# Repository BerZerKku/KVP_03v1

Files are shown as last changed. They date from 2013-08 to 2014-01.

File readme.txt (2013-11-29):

Плата KVP_03v1.
Сделана в OrCAD 16.6.

Предназначена для использования в АВАНТ К400 и АВАНТ Р400М вместе с сэндвич-
панелями.

Основной вариант:
используется для Р400М
отсутствуют: цифровая ретрансляция, выходы ком.ПРД/ПРМ, вход ПУСК

Вариант К400:
используется для К400
плата запаивается полностью

На данный момент входы управления запаиваются под 24В.

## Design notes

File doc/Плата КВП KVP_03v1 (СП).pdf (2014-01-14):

№ | Наименование | Корпус | Кол. | Поз. | Примечание

# 2 АВАНТ КВП v3.1 СП

Изм | Лист | № докум. | Подп. | Дата
Разраб. | Щеблыкин М.В | | 14-01-14 | Плата КВП 03v1 Спецификация | Лит. | Лист | Листов
Провер. | Вершинин А.С. | | | | | 1 | 5

### ООО «Прософт-Системы»

Н.контр. | Назаренко А.Н.
Утв. | Чирков А.Г.

1 Сборочный чертеж
| АВАНТ КВП v3.1 rev.2 | 1

ДЕТАЛИ

3 Плата печатная
| KVP_03v1 | 1

ПРОЧИЕ ИЗДЕЛИЯ

Диоды

5 1N4148WS FAIRCHILD
| (1N4148WS-V VISHAY) | SOD-323 | 2 | VD21,VD24

7 Супрессор SM6T6V8CA 6.8В
| двунаправленный | DO-214AA | 11 | VD1-VD8,VD20,VD23,VD27

9 Супрессор SM6T18A 18В
| однонаправленный | DO-214AA | 2 | VD22,VD25

11 Супрессор SM6T30CA 30В
| двунаправленный | DO-214AA | 1 | VD26

13 Супрессор SMBJ300CA 300B
| двунаправленный | DO-214AA | 2 | VD13,VD14

Конденсаторы

17 | чип 0805 X7R 50В 0.01мкФ ±10% | 0805 | 4 | C5,C8,C14,C17
19 | чип 0805 X7R 50В 0.1мкФ ±10% | 0805 | 14 | C1,C3,C4,C6,C9,C10,C12,C13,C15,C18,
| | | | C28,C29,C32,C34
21 | чип 1206 X7R 50В 0.1мкФ ±10% | 1206 | 2 | C33,C35
23 | чип 1210 X7R 25В 10мкФ ±10% | 1210 | 4 | C2,C7,C11,C16

| | | | | АВАНТ КВП v3.1 | Лист 2 Изм
2
| Лист | № докум. | Подп. | Дата

Микросхемы

27 | ADM2587EBRWZ 500kB AD | SOIC_20 | 2 | DD2,DD4

29 SN74LVC1G14DBV(R, T) TI
| (74LVC1G14GV PANASONIC, NXP) | SOT-23_5 | 2 | DD1,DD3

31 ULN280ADW TI (ULN2803ADWR TI,
| ULN2803AFWG TOSHIBA) | SOIC_18 | 1 | DD7
35 | Оптрон ACPL-M50L-500E AVAGO | SMD_5 | 2 | AV2,AV3

39 Переключатель SmWDL-02
| DIPTRONICS | SMD_4 | 4 | S1-S4

Разъемы

43 | 231-576/001-000 WAGO | 16 pins | 2 | X2,X3
45 | DIN 41612 3*32 64 MR | 64 pins | 1 | X1 | вилка угловая
47 | PLS-2 | PLS_2 | 2 | X4,X5

Резисторы

51 | чип 0805 10Ом ±5% | 0805 | 8 | R5,R8-R10,R17,R20-R22
53 | чип 0805 51Ом ±5% | 0805 | 2 | R6,R18
55 | чип 0805 100Ом ±5% | 0805 | 4 | R3,R4,R15,R16 | не устанавл.
57 | чип 0805 120Ом ±5% | 0805 | 2 | R7,R19
59 | чип 0805 470Ом ±5% | 0805 | 4 | R11,R12,R23,R24
61 | чип 2010 470Ом ±5% | 2010 | 4 | R49,R56,R57,R64
63 | чип 2010 1кОм ±5% | 2010 | 4 | R51,R54,R59,R62
65 | чип 2010 1.2кОм ±5% | 2010 | 2 | R52,R60
67 | чип 0805 2кОм ±5% | 0805 | 2 | R53,R61

| | | | 3 Изм
Лист | № докум. | Подп. | Дата

69 SQM500JB-5K1 5.1кОм 5Вт ±5%
| YAGEO | 2 pins | 6 | R42,R47,R50,R55,R58,R63 | не устанавл.
71 | чип 0805 6.2кОм ±5% | 0805 | 1 | R37
73 | чип 0805 10кОм ±5% | 0805 | 4 | R1,R2,R13,R14

77 Реле D3212 FX2 24VDC AXICOM
| (G6S-2-24DC OMRON) | 8 pins | 1 | K1

81 Ферритовая бусина
| BLM31PG601SN1 MURATA | 1206 | 8 | FB1-FB8
83 | Провод МГТФ 0.05 (0.03-0.12) | 0.2м | для доработки

Переменные данные для
исполнений:

ВАРИАНТ К400

Диоды

5 1N4148WS FAIRCHILD
| (1N4148WS-V VISHAY) | SOD-323 | 1 | VD19

7 Супрессор SM6T6V8CA 6.8В
| двунаправленный | DO-214AA | 5 | VD9-VD12,VD17

9 Супрессор SM6T18A 18В
| однонаправленный | DO-214AA | 1 | VD18

13 Супрессор SMBJ300CA 300B
| двунаправленный | DO-214AA | 3 | VD14-VD16

Конденсаторы

17 | чип 0805 X7R 50В 0.01мкФ ±10% | 0805 | 2 | C23,C26
19 | чип 0805 X7R 50В 0.1мкФ ±10% | 0805 | 6 | C19,C21,C22,C24,C27,C30
21 | чип 1206 X7R 50В 0.1мкФ ±10% | 1206 | 1 | C31
23 | чип 1210 X7R 25В 10мкФ ±10% | 1210 | 2 | C20,C25

| | | | 4 Изм
Лист | № докум. | Подп. | Дата

Микросхемы

27 | ADM2587EBRWZ 500kB AD | SOIC_20 | 1 | DD6

29 SN74LVC1G14DBV(R, T) TI
| (74LVC1G14GV PANASONIC, NXP) | SOT-23_5 | 1 | DD5
35 | Оптрон ACPL-M50L-500E AVAGO | SMD_5 | 1 | AV1

39 Переключатель SmWDL-02
| DIPTRONICS | SMD_4 | 2 | S5,S6

Резисторы

51 | чип 0805 10Ом ±5% | 0805 | 4 | R29,R32-R34
53 | чип 0805 51Ом ±5% | 0805 | 1 | R30
55 | чип 0805 100Ом ±5% | 0805 | 2 | R27,R28
57 | чип 0805 120Ом ±5% | 0805 | 1 | R31
59 | чип 0805 470Ом ±5% | 0805 | 2 | R35,R36
61 | чип 2010 470Ом ±5% | 2010 | 2 | R41,R48
63 | чип 2010 1кОм ±5% | 2010 | 2 | R45,R46
65 | чип 2010 1.2кОм ±5% | 2010 | 1 | R43
67 | чип 0805 2кОм ±5% | 0805 | 1 | R44
71 | чип 0805 6.2кОм ±5% | 0805 | 3 | R38-R40
73 | чип 0805 10кОм ±5% | 0805 | 2 | R25,R26

77 Реле D3212 FX2 24VDC AXICOM
| (G6S-2-24DC OMRON) | 8 pins | 3 | К2-K4

81 Ферритовая бусина
| BLM31PG601SN1 MURATA | 1206 | 4 | FB9-FB12

| | | | 5 Изм
Лист | № докум. | Подп. | Дата

### Лист регистрции ревизий СП

№ ревизии | № замененных (измененных) страниц | Дата ревизии | Краткое содержание и причина внесения изменений | Примечание
0 | вновь | 28.11.13
1 | 1-4 | 13.12.13 | Элементы K2 поз.77, VD14 поз.13, R38-R40 поз.71 перенесены в вариант К400.
2 | 1,3 | 09.01.14 | Добавлен провод поз.83 Поз.55 в основом варианте не устанавливать. Изменен номер ревизии СБ.

### Лист регистрции ревизий СБ

№ ревизии | № замененных (измененных) страниц | Дата ревизии | Краткое содержание и причина внесения изменений | Примечание
0 | вновь | 28.11.13
1 | 1 | 13.12.13 | Наименование документа изменено на «Плата КВП 03v1».
2 | 1 | 09.01.14 | Добавлена доработка сигналов телемеханики и локальной сети. Добавлена доработка подтяжек в интерфейсах.

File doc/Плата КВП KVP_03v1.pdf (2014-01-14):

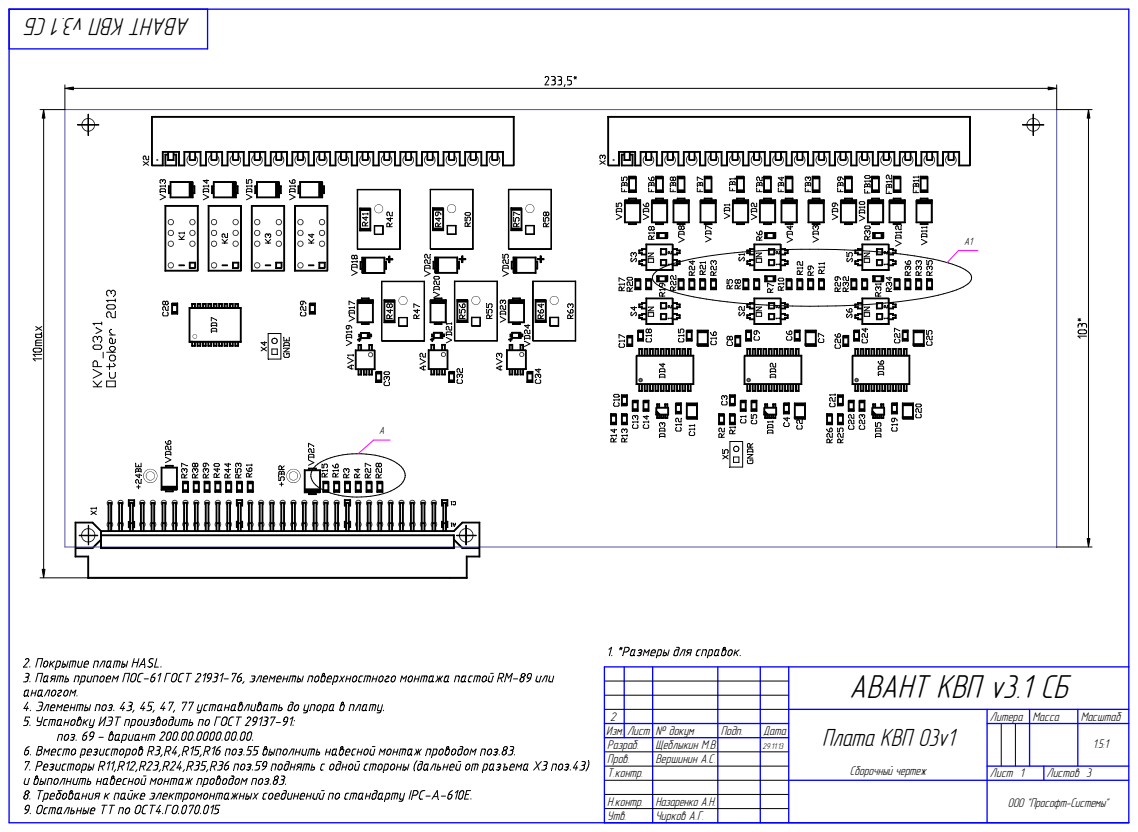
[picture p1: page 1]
Ëèñòîâ 3; Ìàññà; Ìàñøòàá; Ïîäï.; Äàòà; Óòâ.; Í.êîíòð.; Ò.êîíòð.; Ïðîâ.; Ðàçðàá.; Èçì. Ëèñò; ×èðêîâ À.Ã.; Íàçàðåíêî À.Í.; Âåðøèíèí À.Ñ.; Ùåáëûêèí Ì.Â.; № äîêóì; Ëèñò 1; Ëèòåðà; Ïëàòà ÊÂÏ 03v1

ÀÂÀÍÒ ÊÂÏ v3.1 ÑÁ

Ñáîðî÷íûé ÷åðòåæ

ÎÎÎ "Ïðîñîôò-Ñèñòåìû"

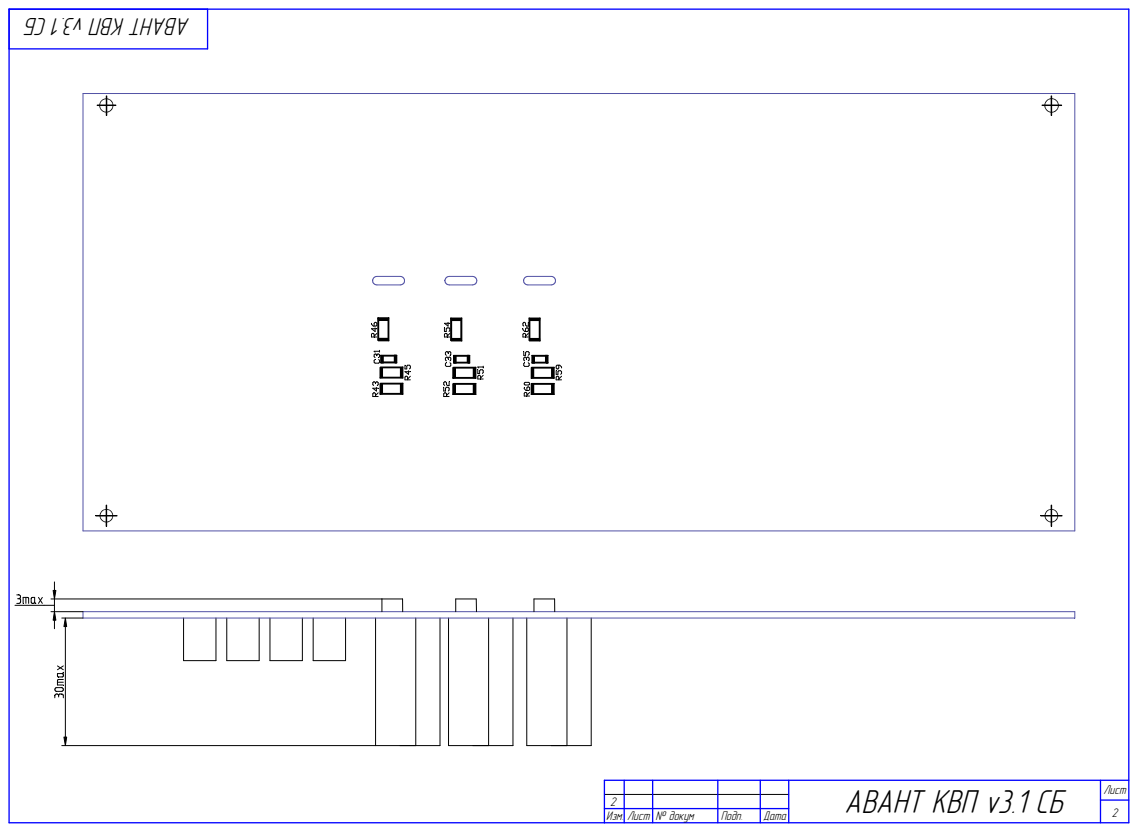
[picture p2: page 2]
Ëèñò; Èçì. Ëèñò № äîêóì; Ïîäï.; Äàòà; ÀÂÀÍÒ ÊÂÏ v3.1 ÑÁ

À (5:1), ï.6

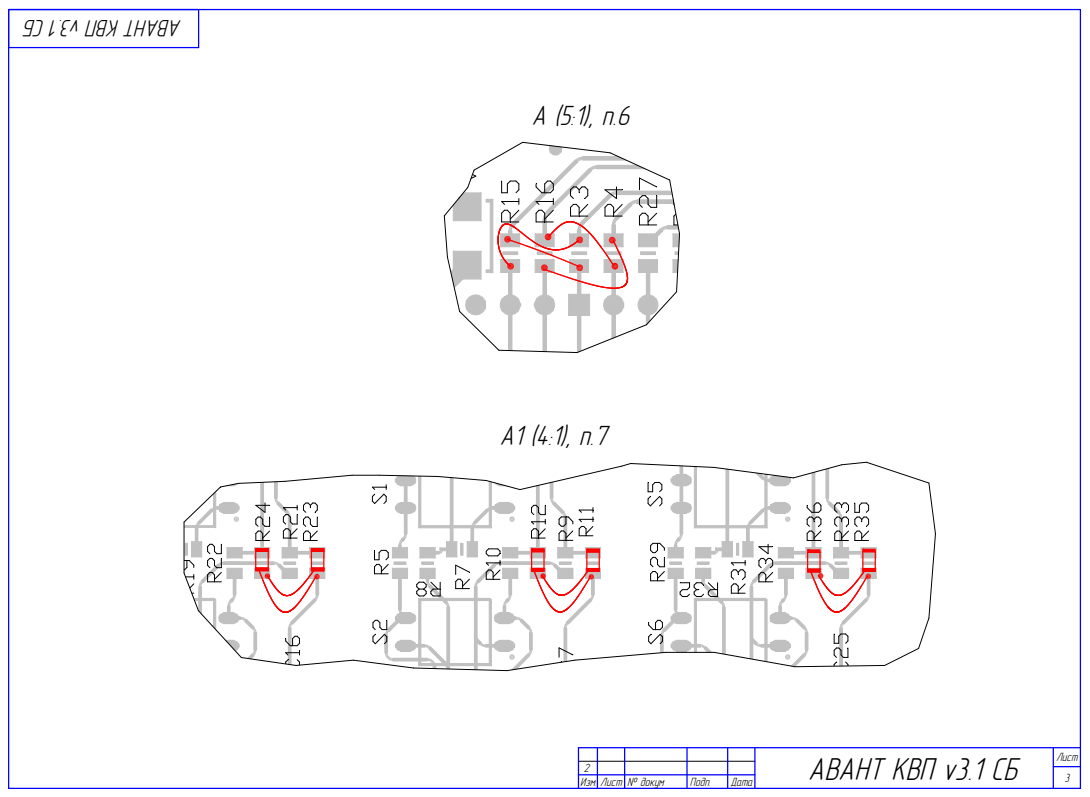
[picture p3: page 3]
Ëèñò; Èçì. Ëèñò № äîêóì; Ïîäï.; Äàòà; ÀÂÀÍÒ ÊÂÏ v3.1 ÑÁ

№ | Наименование | Корпус | Кол. | Поз. | Примечание

# 2 АВАНТ КВП v3.1 СП

Изм | Лист | № докум. | Подп. | Дата
Разраб. | Щеблыкин М.В | | 14-01-14 | Плата КВП 03v1 Спецификация | Лит. | Лист | Листов
Провер. | Вершинин А.С. | | | | | 1 | 5

### ООО «Прософт-Системы»

Н.контр. | Назаренко А.Н.
Утв. | Чирков А.Г.

1 Сборочный чертеж
| АВАНТ КВП v3.1 rev.2 | 1

ДЕТАЛИ

3 Плата печатная
| KVP_03v1 | 1

ПРОЧИЕ ИЗДЕЛИЯ

Диоды

5 1N4148WS FAIRCHILD
| (1N4148WS-V VISHAY) | SOD-323 | 2 | VD21,VD24

7 Супрессор SM6T6V8CA 6.8В
| двунаправленный | DO-214AA | 11 | VD1-VD8,VD20,VD23,VD27

9 Супрессор SM6T18A 18В
| однонаправленный | DO-214AA | 2 | VD22,VD25

11 Супрессор SM6T30CA 30В
| двунаправленный | DO-214AA | 1 | VD26

13 Супрессор SMBJ300CA 300B
| двунаправленный | DO-214AA | 2 | VD13,VD14

Конденсаторы

17 | чип 0805 X7R 50В 0.01мкФ ±10% | 0805 | 4 | C5,C8,C14,C17
19 | чип 0805 X7R 50В 0.1мкФ ±10% | 0805 | 14 | C1,C3,C4,C6,C9,C10,C12,C13,C15,C18,
| | | | C28,C29,C32,C34
21 | чип 1206 X7R 50В 0.1мкФ ±10% | 1206 | 2 | C33,C35
23 | чип 1210 X7R 25В 10мкФ ±10% | 1210 | 4 | C2,C7,C11,C16

| | | | | АВАНТ КВП v3.1 | Лист 2 Изм
2
| Лист | № докум. | Подп. | Дата

Микросхемы

27 | ADM2587EBRWZ 500kB AD | SOIC_20 | 2 | DD2,DD4

29 SN74LVC1G14DBV(R, T) TI
| (74LVC1G14GV PANASONIC, NXP) | SOT-23_5 | 2 | DD1,DD3

31 ULN280ADW TI (ULN2803ADWR TI,
| ULN2803AFWG TOSHIBA) | SOIC_18 | 1 | DD7
35 | Оптрон ACPL-M50L-500E AVAGO | SMD_5 | 2 | AV2,AV3

39 Переключатель SmWDL-02
| DIPTRONICS | SMD_4 | 4 | S1-S4

Разъемы

43 | 231-576/001-000 WAGO | 16 pins | 2 | X2,X3
45 | DIN 41612 3*32 64 MR | 64 pins | 1 | X1 | вилка угловая
47 | PLS-2 | PLS_2 | 2 | X4,X5

Резисторы

51 | чип 0805 10Ом ±5% | 0805 | 8 | R5,R8-R10,R17,R20-R22
53 | чип 0805 51Ом ±5% | 0805 | 2 | R6,R18
55 | чип 0805 100Ом ±5% | 0805 | 4 | R3,R4,R15,R16 | не устанавл.
57 | чип 0805 120Ом ±5% | 0805 | 2 | R7,R19
59 | чип 0805 470Ом ±5% | 0805 | 4 | R11,R12,R23,R24
61 | чип 2010 470Ом ±5% | 2010 | 4 | R49,R56,R57,R64
63 | чип 2010 1кОм ±5% | 2010 | 4 | R51,R54,R59,R62
65 | чип 2010 1.2кОм ±5% | 2010 | 2 | R52,R60
67 | чип 0805 2кОм ±5% | 0805 | 2 | R53,R61

| | | | 3 Изм
Лист | № докум. | Подп. | Дата

69 SQM500JB-5K1 5.1кОм 5Вт ±5%
| YAGEO | 2 pins | 6 | R42,R47,R50,R55,R58,R63 | не устанавл.
71 | чип 0805 6.2кОм ±5% | 0805 | 1 | R37
73 | чип 0805 10кОм ±5% | 0805 | 4 | R1,R2,R13,R14

77 Реле D3212 FX2 24VDC AXICOM
| (G6S-2-24DC OMRON) | 8 pins | 1 | K1

81 Ферритовая бусина
| BLM31PG601SN1 MURATA | 1206 | 8 | FB1-FB8
83 | Провод МГТФ 0.05 (0.03-0.12) | 0.2м | для доработки

Переменные данные для
исполнений:

ВАРИАНТ К400

Диоды

5 1N4148WS FAIRCHILD
| (1N4148WS-V VISHAY) | SOD-323 | 1 | VD19

7 Супрессор SM6T6V8CA 6.8В
| двунаправленный | DO-214AA | 5 | VD9-VD12,VD17

9 Супрессор SM6T18A 18В
| однонаправленный | DO-214AA | 1 | VD18

13 Супрессор SMBJ300CA 300B
| двунаправленный | DO-214AA | 3 | VD14-VD16

Конденсаторы

17 | чип 0805 X7R 50В 0.01мкФ ±10% | 0805 | 2 | C23,C26
19 | чип 0805 X7R 50В 0.1мкФ ±10% | 0805 | 6 | C19,C21,C22,C24,C27,C30
21 | чип 1206 X7R 50В 0.1мкФ ±10% | 1206 | 1 | C31
23 | чип 1210 X7R 25В 10мкФ ±10% | 1210 | 2 | C20,C25

| | | | 4 Изм
Лист | № докум. | Подп. | Дата

Микросхемы

27 | ADM2587EBRWZ 500kB AD | SOIC_20 | 1 | DD6

29 SN74LVC1G14DBV(R, T) TI
| (74LVC1G14GV PANASONIC, NXP) | SOT-23_5 | 1 | DD5
35 | Оптрон ACPL-M50L-500E AVAGO | SMD_5 | 1 | AV1

39 Переключатель SmWDL-02
| DIPTRONICS | SMD_4 | 2 | S5,S6

Резисторы

51 | чип 0805 10Ом ±5% | 0805 | 4 | R29,R32-R34
53 | чип 0805 51Ом ±5% | 0805 | 1 | R30
55 | чип 0805 100Ом ±5% | 0805 | 2 | R27,R28
57 | чип 0805 120Ом ±5% | 0805 | 1 | R31
59 | чип 0805 470Ом ±5% | 0805 | 2 | R35,R36
61 | чип 2010 470Ом ±5% | 2010 | 2 | R41,R48
63 | чип 2010 1кОм ±5% | 2010 | 2 | R45,R46
65 | чип 2010 1.2кОм ±5% | 2010 | 1 | R43
67 | чип 0805 2кОм ±5% | 0805 | 1 | R44
71 | чип 0805 6.2кОм ±5% | 0805 | 3 | R38-R40
73 | чип 0805 10кОм ±5% | 0805 | 2 | R25,R26

77 Реле D3212 FX2 24VDC AXICOM
| (G6S-2-24DC OMRON) | 8 pins | 3 | К2-K4

81 Ферритовая бусина
| BLM31PG601SN1 MURATA | 1206 | 4 | FB9-FB12

| | | | 5 Изм
Лист | № докум. | Подп. | Дата

### Лист регистрции ревизий СП

№ ревизии | № замененных (измененных) страниц | Дата ревизии | Краткое содержание и причина внесения изменений | Примечание
0 | вновь | 28.11.13
1 | 1-4 | 13.12.13 | Элементы K2 поз.77, VD14 поз.13, R38-R40 поз.71 перенесены в вариант К400.
2 | 1,3 | 09.01.14 | Добавлен провод поз.83 Поз.55 в основом варианте не устанавливать. Изменен номер ревизии СБ.

### Лист регистрции ревизий СБ

№ ревизии | № замененных (измененных) страниц | Дата ревизии | Краткое содержание и причина внесения изменений | Примечание
0 | вновь | 28.11.13
1 | 1 | 13.12.13 | Наименование документа изменено на «Плата КВП 03v1».
2 | 1 | 09.01.14 | Добавлена доработка сигналов телемеханики и локальной сети. Добавлена доработка подтяжек в интерфейсах.

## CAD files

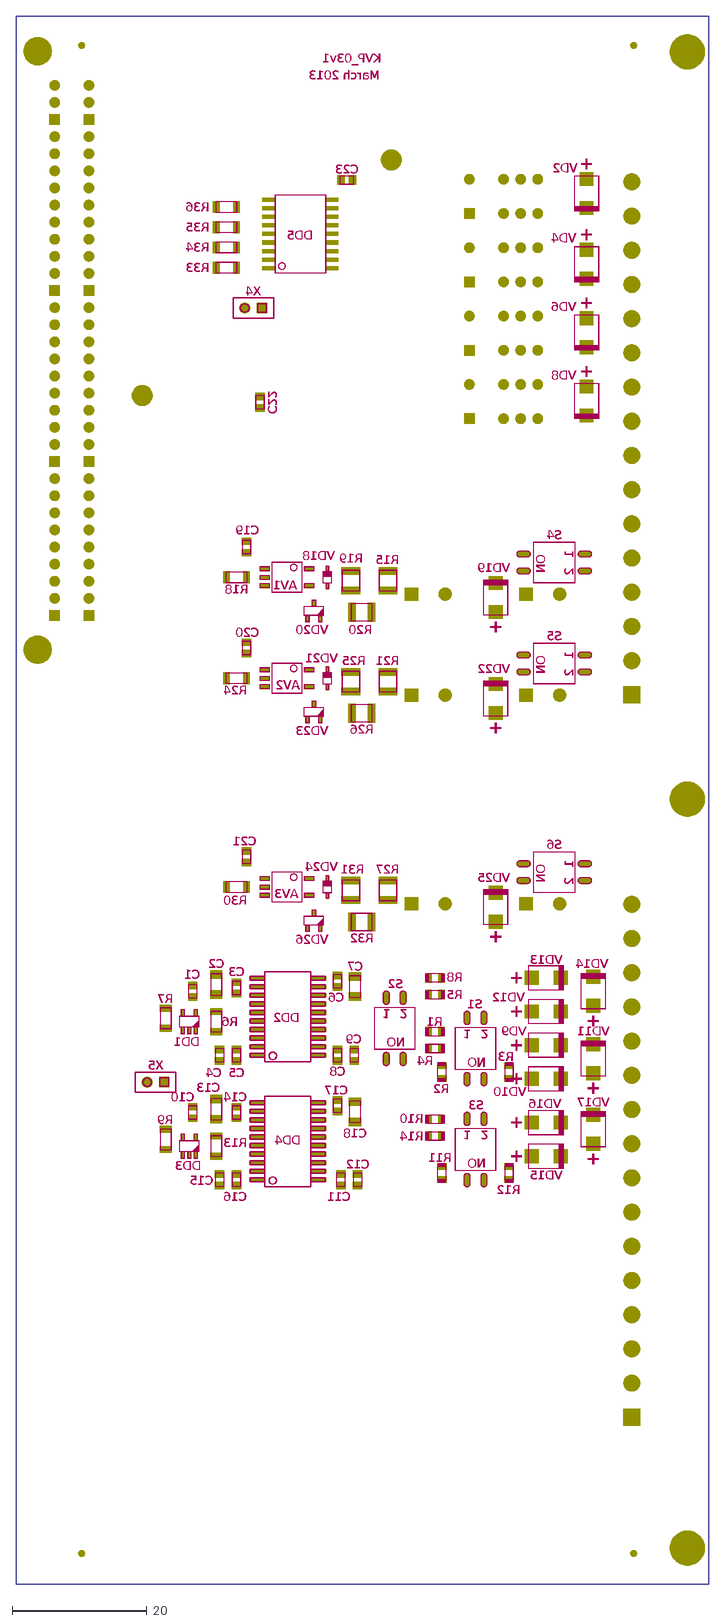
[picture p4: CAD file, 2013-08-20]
doc/bot.dxf
X5
X4
DD5
R14
R12
R11
R10
R1
R8
R5
R4
R3
R2
DD4
DD2
DD3
DD1
C18
C13
C7
C2
C23
C22
C17
C16
C15
C14
C12
C11
C10
C9
C8
C6
C5
C4
C3
C1
C21
C20
C19
R36
R35
R34
R33
R13
R9
R7
R6
R30
R24
R18
VD24
VD21
VD18
VD26
VD23
VD20
S3
1
2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

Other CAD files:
doc/Плата КВП KVP_03v1 (СБ).dwg

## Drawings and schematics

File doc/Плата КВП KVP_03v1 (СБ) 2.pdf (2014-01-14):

Ëèñò; Èçì. Ëèñò № äîêóì; Ïîäï.; Äàòà; ÀÂÀÍÒ ÊÂÏ v3.1 ÑÁ

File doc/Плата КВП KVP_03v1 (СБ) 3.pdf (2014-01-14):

À (5:1), ï.6

Ëèñò; Èçì. Ëèñò № äîêóì; Ïîäï.; Äàòà; ÀÂÀÍÒ ÊÂÏ v3.1 ÑÁ

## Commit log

2013-03-06 Начата прорисовка схемы.
    [KVP_03V1.DSN]
2013-03-06 Прорисованы RS422 и RS485 интерфейсы.
    [KVP_03V1.DSN]
2013-03-07 Начата прорисовка дискретных входов.
    [KVP_03V1.DSN]
2013-03-11 Прорисованы дискретные входы.
    [KVP_03V1.DSN]
2013-03-13 Расставлены элементы. Прикинута разводка.
    [KVP_03V1.DSN, kvp_03v1.brd]
2013-03-14 Продвигается разводка платы.
    [KVP_03V1.DSN, kvp_03v1.brd]
2013-03-14 Осталось только причесать. Элементы расположены на слое BOTTOM.
    [KVP_03V1.DSN, kvp_03v1.brd]
2013-03-15 Завершена разводка. Подготовлены файлы для производства.
    [KVP_03V1.DSN, art_param.txt, kvp_03v1.brd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]
2013-03-15 Изменен входной каскад. Добавлена шелкография для положения переключателей. Надо: 1. Добавить супрессоров по питанию. 2. Сгенерировать файлы для производства.
    [KVP_03V1.DSN, kvp_03v1.brd]
2013-03-18 Заменена площадка для оптрона. Дорисована шелкография для переключателей. Сформированы все файлы для производства.
    [KVP_03V1.DSN, kvp_03v1.brd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]
2013-03-18 Сдвинуты надписи "D - IINPUT" у иерархических блоков.
    [KVP_03V1.DSN]
2013-08-19 Переделана схема, на листах с основной надписью.
    [KVP_03V1.DSN]
2013-08-20 Добавлена документация, просто для аттестации.
    [KVP_03V1.DSN, bot.dxf, top.dxf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]
2013-10-12 Добавлен файл описания.
2013-10-12 Исправление внешних сигналов клеммников и подключения интерфейсов.
    [KVP_03V1.DSN]
2013-10-13 Начата расстановка входов/выходов.
    [KVP_03V1.DSN, kvp_03v1.brd]
2013-10-13 Ведется разовдка входных цепей.
    [KVP_03V1.DSN, kvp_03v1.brd]
2013-10-14 расставлены входы/выходы, начата расстановка интерфейсов
    [KVP_03V1.DSN, kvp_03v1.brd]
2013-10-14 Заменены элементы на аналоги из базы. Добавлены резисторы в Rx/Tx интерфейсов. Немного продвинулась разводка.
    [KVP_03V1.DSN, kvp_03v1.brd]
2013-10-15 Ведется разводка интерфейсной части.
    [KVP_03V1.DSN, kvp_03v1.brd]
2013-10-17 Плата разведена, началась прическа.
    [KVP_03V1.DSN, kvp_03v1.brd]
2013-10-17 Развернуты конденсаторы на 422 интерфейсе.
    [kvp_03v1.brd]
2013-10-19 Изменены габариты платы и крепежные отверстия.
    [KVP_03V1.DSN, kvp_03v1.brd]
2013-10-21 Исправлено название платы в шапке перечня элементов.
2013-10-21 Убрано лишнее соединение на X1.C3. На плате подчищены лишние проводники. Добавлена шелкография с описаниями переключателей.
    [KVP_03V1.DSN, kvp_03v1.brd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]
2013-10-21 Проведено сглаживаение линий.
    [kvp_03v1.brd]
2013-10-22 Исправлены слои сборки.
    [kvp_03v1.brd]
2013-10-22 Подготовлены файлы для производства.
    [kvp_03v1.brd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]
2013-10-22 На плате добавлены вырезы под оптронами. Файлы переданы за заказ.
    [kvp_03v1.brd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]
2013-11-28 На схеме элементы обновлены из базы, супрессоры P6SMB заменены на аналоги. Добавлена спецификация.
    [KVP_03V1.DSN]
2013-11-28 Сделано вариантное исполнение "К400".
    [KVP_03V1.DSN]
2013-11-28 В файл описания добавлены вариантные исполнения.
2013-11-29 Из СП убраны 5Вт резисторы в цепи управления. Т.е. будут паяться 24В вариант. Удалены документы подготовленные для аттестации, не отвечающие действительности. Добавлен сборочный чертеж.
    [top.dxf, Плата KVP_03v1 (СБ).dwg, Плата КВП KVP_03v1 (СБ).dwg]
2013-12-02 В СП добавлена таблица ревизий для СБ. В СБ изменен размер ширины платы.
    [Плата КВП KVP_03v1 (СБ).dwg]
2013-12-02 Добавлен файл ограничений.
2013-12-02 Изменен масштаб на сборочнике на 1:1.
    [Плата КВП KVP_03v1 (СБ).dwg]
2013-12-03 Внесены исправления по замечаниям Боковой Т.И.
    [Плата КВП KVP_03v1 (СБ).dwg]
2013-12-03 Изменены поз.обозначения для поз.69
2013-12-13 Элементы в цепи "Предупреждение" перенесены в вариант К400.
    [KVP_03V1.DSN]
2013-12-13 Изменено название изделия в СБ. Выход "Предупреждение" перенесен в вариант К400.
    [Плата КВП KVP_03v1 (СБ).dwg]
2013-12-21 В СП исправлена ревизия СБ. Документация подписана Назаренко и отправлена Боковой.
2014-01-14 На плате найдены ошибки: перепутаны местами сигналы локальной сети и телемеханики, не туда подтянуты выходы интерфейсов Z и Y.
    Добавлены доработки в сп/сб.
    [Плата КВП KVP_03v1 (СБ).dwg]
2014-01-14 В СП подправлена версия ревизии.
